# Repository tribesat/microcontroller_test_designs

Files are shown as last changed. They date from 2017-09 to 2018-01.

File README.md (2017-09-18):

# microcontroller_test_designs
Practice designing and manufacturing microcontroller boards

# License Information

The hardware is released under [Creative Commons Share-alike 3.0](http://creativecommons.org/licenses/by-sa/3.0/).  

## ATmega328P_QFP

These desgines are adapted from the [Sparkfun Arduino Pro Mini](https://github.com/sparkfun/Arduino_Pro_Mini_328)

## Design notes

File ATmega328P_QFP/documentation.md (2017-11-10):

# ATmega328P Quad Flat Pack (QFP)

This board was designed by the Tribesat Project in 2016. The purpose of this design was to test our ability to manufacture a board with an ATmega328P in a quad flat pack package.

The ATmega328P is an 8-bit AVR microcontroller. More information about it can be found [here](http://www.microchip.com/wwwproducts/en/ATmega328P).

The board desgine is derivied from the [Sparkfun Arduino Pro Mini](https://learn.sparkfun.com/tutorials/using-the-arduino-pro-mini-33v). The main difference between that board and this one is the removal of the voltage regulator and physical reset button. The pin out on this board is the same as the Arduino Pro Mini pin out.

This design can work with a 8Mhz or 16Mhz oscillator. If 16Mhz is used power the board at 5V, if 8Mhz is used the board may be powered at 3.3V.

Power must be regulated before entering into this board.

To reset the board, briefly short one of the RST pins to ground. The RST pins are  pulled high with a 10k resistor.

A green LED is connected to pin 13 for trouble shoting purposes. There is not power indicator LED.

The traces on the board are 0.01" and the vias have 0.02" drill holes. This is more than sufficient to handle the current through the traces. Right angles in the data traces have been avoided wherever possible.

The bottom and top layers of the board contain ground pours. These pores are connected through the GND pins and vias. These pores both insure good grounding in the board and isolate the oscillator from noise.

Decoupling capacitors were added as near to the chips as possible to minimize noise. This is detailed in the relevant data sheets.

0603 package size is used for all passive components. This size was selected because I believe it to be a good compromise between size and ease of placement.  The exception to this is the 10uF capacitor, which necessitated a larger package size.

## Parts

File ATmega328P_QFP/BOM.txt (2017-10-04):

component/value, size, quanity, digikey part number
--------------------------------------------------------
ATmega328P, 32-TQFP, 1, ATMEGA328P-AURCT-ND
8MHz Resonator, 3-SMD, 1, 490-1195-1-ND
0.1uF Capacitor, 0603, 4, 311-1088-1-ND
10uF Polarized Capacitor, 1206, 1, 478-1654-1-ND
10k Resistor, 0603, 1, 311-10.0KHRCT-ND
330 Resistor, 0603, 1, 311-330HRCT-ND
Green LED, 0603, 1, 350-2035-1-ND

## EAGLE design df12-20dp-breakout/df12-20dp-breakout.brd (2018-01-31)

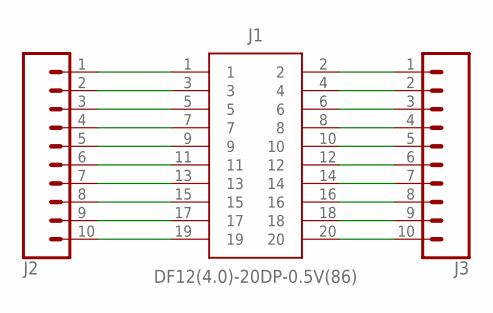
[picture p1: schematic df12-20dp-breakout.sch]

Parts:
J1: DF12(4.0)-20DP-0.5V(86); DF12(4.0)-20DP
J2, J3: CONN_10LOCK_LONGPADS; 1X10_LOCK_LONGPADS

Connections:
unnamed: J1.17, J2.9
unnamed: J1.15, J2.8
unnamed: J1.13, J2.7
unnamed: J1.11, J2.6
unnamed: J1.9, J2.5
unnamed: J1.7, J2.4
unnamed: J1.19, J2.10
unnamed: J1.5, J2.3
unnamed: J1.3, J2.2
unnamed: J1.1, J2.1
unnamed: J1.2, J3.1
unnamed: J1.4, J3.2
unnamed: J1.6, J3.3
unnamed: J1.8, J3.4
unnamed: J1.10, J3.5
unnamed: J1.12, J3.6
unnamed: J1.14, J3.7
unnamed: J1.16, J3.8
unnamed: J1.18, J3.9
unnamed: J1.20, J3.10

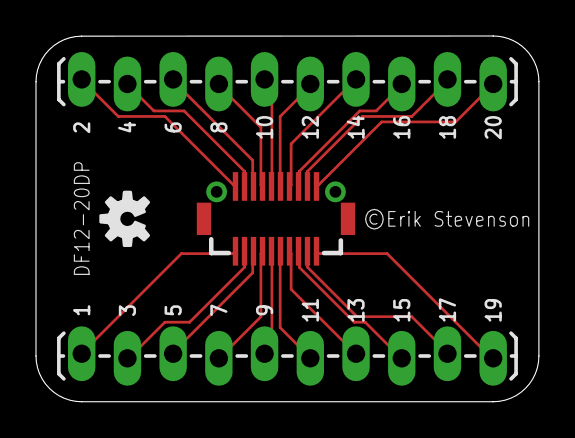
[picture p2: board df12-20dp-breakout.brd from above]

Board: 2 copper layers, 27.9 x 20.3 mm, 4 parts (0 on the bottom side), 20 nets.

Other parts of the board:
U$1: OSHW-LOGO-S

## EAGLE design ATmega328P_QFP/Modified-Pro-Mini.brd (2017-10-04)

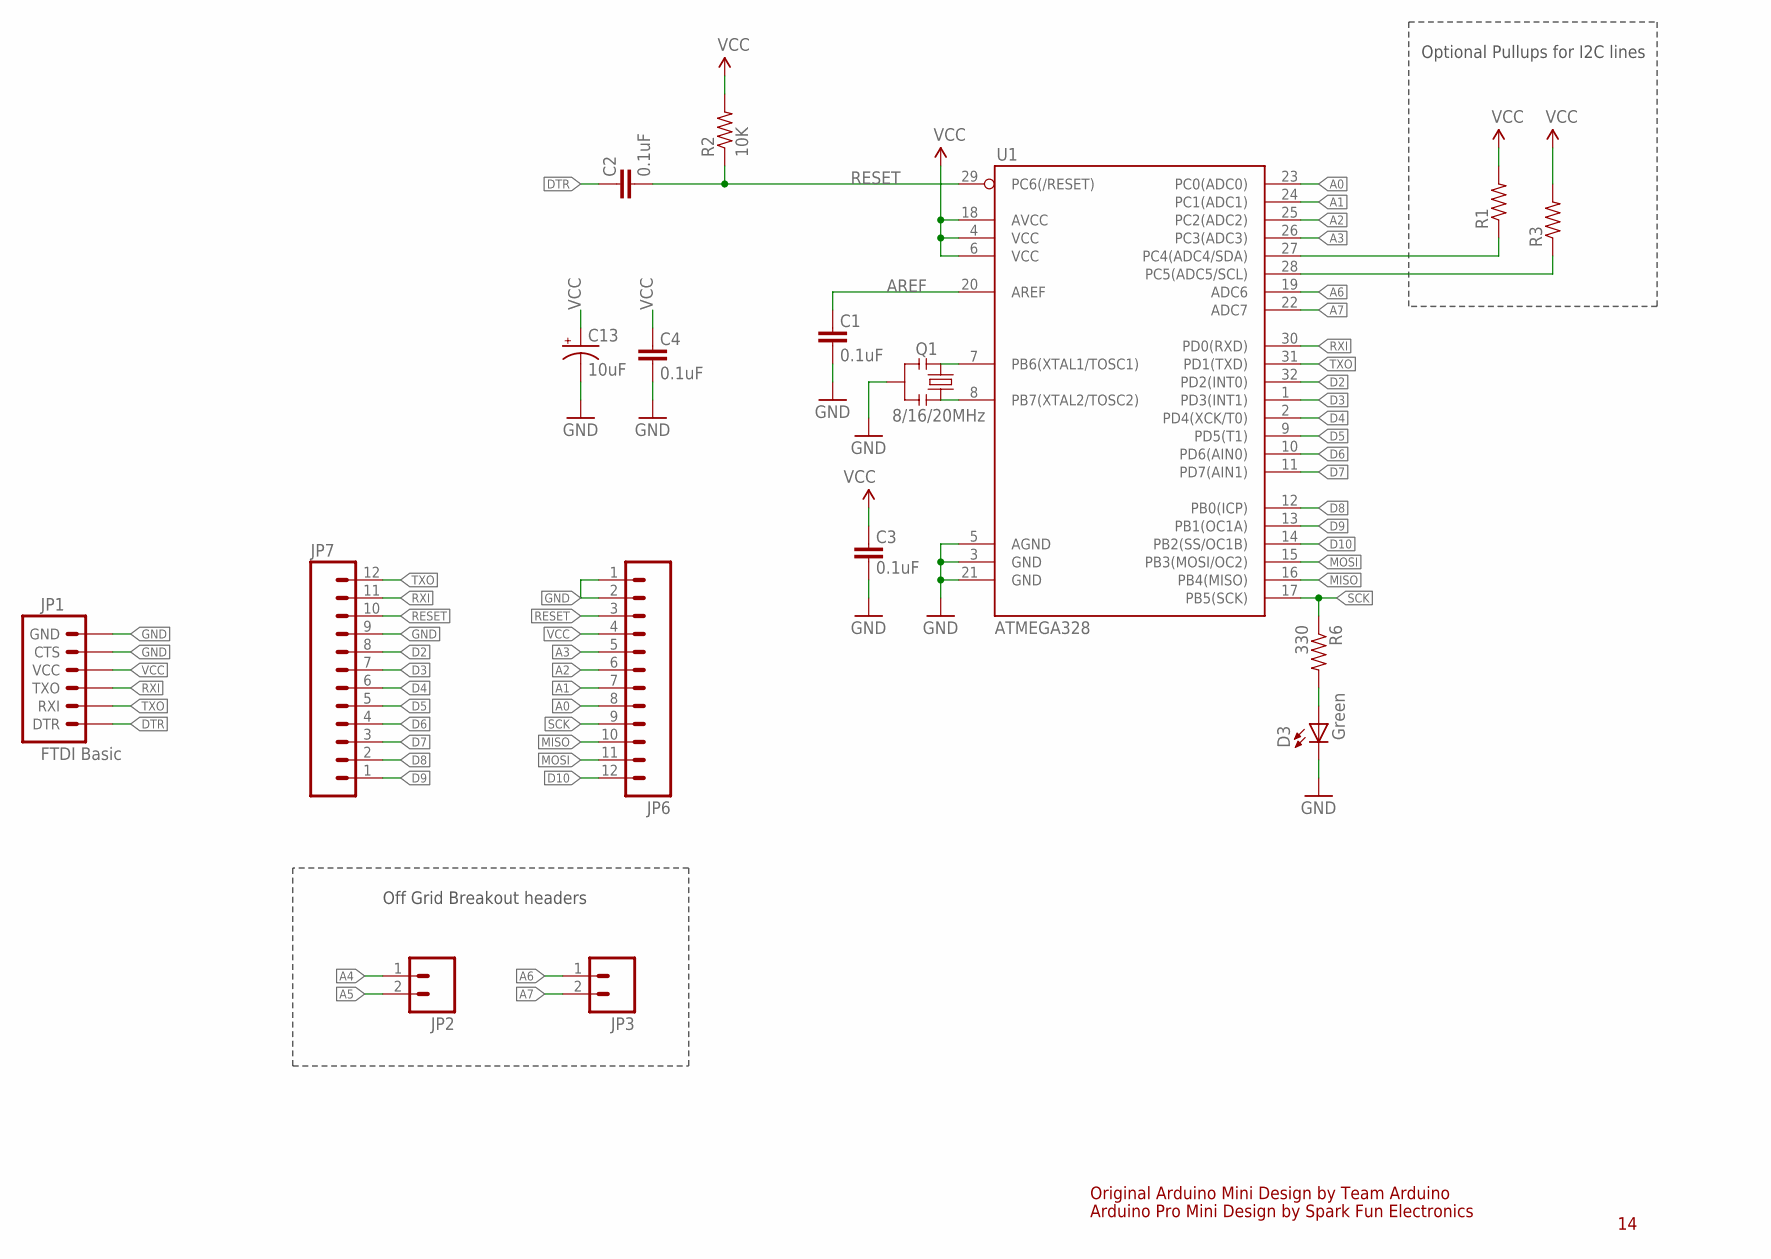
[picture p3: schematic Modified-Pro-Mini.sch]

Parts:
C1, C2, C3, C4: 0.1uF; 0603-CAP
C13: 10uF; EIA3216
D3: Green; 0603-LED-ALT1
JP1: FTDI Basic; 1X06
JP2, JP3: M02PTH; 1X02
JP6, JP7: M12PTH; 1X12
Q1: 8/16/20MHz; RESONATOR-SMD-1:1
R1, R3: RESISTOR0603-RES; 0603-RES
R2: 10K; 0603-RES
R6: 330; 0603-RES
U1: ATMEGA328; TQFP32-08

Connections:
A0: JP6.8, U1.23 (PC0(ADC0))
A1: JP6.7, U1.24 (PC1(ADC1))
A2: JP6.6, U1.25 (PC2(ADC2))
A3: JP6.5, U1.26 (PC3(ADC3))
A4: JP2.1, R1.1, U1.27 (PC4(ADC4/SDA))
A5: JP2.2, R3.1, U1.28 (PC5(ADC5/SCL))
A6: JP3.1, U1.19 (ADC6)
A7: JP3.2, U1.22 (ADC7)
AREF: C1.2, U1.20 (AREF)
D2: JP7.8, U1.32 (PD2(INT0))
D3: JP7.7, U1.1 (PD3(INT1))
D4: JP7.6, U1.2 (PD4(XCK/T0))
D5: JP7.5, U1.9 (PD5(T1))
D6: JP7.4, U1.10 (PD6(AIN0))
D7: JP7.3, U1.11 (PD7(AIN1))
D8: JP7.2, U1.12 (PB0(ICP))
D9: JP7.1, U1.13 (PB1(OC1A))
D10: JP6.12, U1.14 (PB2(SS/OC1B))
DTR: C2.2, JP1.1 (DTR)
GND: C1.1, C3.1, C4.1, C13.C (-), D3.C, JP1.5 (CTS), JP1.6 (GND), JP6.1, JP6.2, JP7.9, Q1.2, U1.3 (GND), U1.5 (AGND), U1.21 (GND)
MISO: JP6.10, U1.16 (PB4(MISO))
MOSI: JP6.11, U1.15 (PB3(MOSI/OC2))
unnamed: Q1.3, U1.8 (PB7(XTAL2/TOSC2))
unnamed: Q1.1, U1.7 (PB6(XTAL1/TOSC1))
unnamed: D3.A, R6.2
RESET: C2.1, JP6.3, JP7.10, R2.1, U1.29 (PC6(/RESET))
RXI: JP1.3 (TXO), JP7.11, U1.30 (PD0(RXD))
SCK: JP6.9, R6.1, U1.17 (PB5(SCK))
TXO: JP1.2 (RXI), JP7.12, U1.31 (PD1(TXD))
VCC: C3.2, C4.2, C13.A (+), JP1.4 (VCC), JP6.4, R1.2, R2.2, R3.2, U1.4 (VCC), U1.6 (VCC), U1.18 (AVCC)

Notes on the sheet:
Original Arduino Mini Design by Team Arduino
Arduino Pro Mini Design by Spark Fun Electronics
Optional Pullups for I2C lines
Off Grid Breakout headers

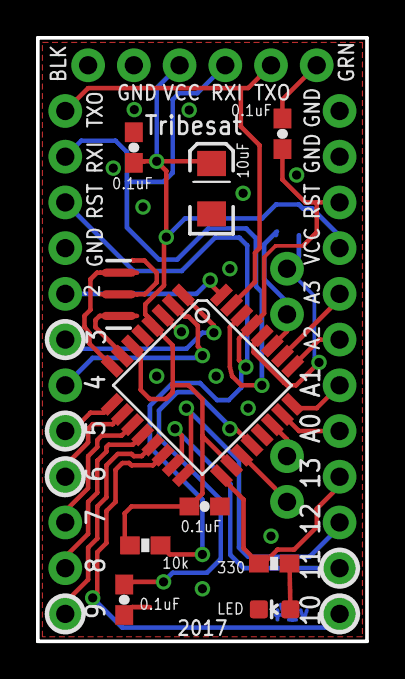
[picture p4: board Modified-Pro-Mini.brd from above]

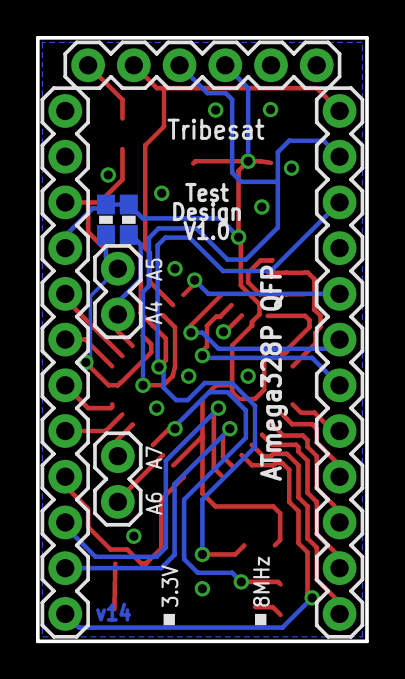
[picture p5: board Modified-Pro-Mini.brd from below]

Board: 2 copper layers, 18.3 x 33.5 mm, 17 parts (7 on the bottom side), 30 nets.

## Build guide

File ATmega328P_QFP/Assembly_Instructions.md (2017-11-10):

# Assembly Instructions

1. Clean PCB, stencil, jig, and tools with IPA
2. Place PCB into jig, and tape the jig together
3. Aligne the stencil with the PCB, and firmly tape the stencil onto the jig
4. Lightly tape the jig onto the table
5. Put a blop of solder paste onto the stencil near the slots for the 328p
6. Use the solder paste spreader to spread the blob of solder paste over the sentencil. Start by bring the paste over the 328p slots and then move outward on the sentencil to the other components
7. Remove the stencil from the jig
   * Be carful not to smear the paste during this process
8. Remove the jig from around the PCB
9. Use exacto knife and dental picks to clean up solder paste
   * Try to get a little bit of seperation between the solder paste on each pad
   * Make sure the solder paste isn't going to flow onto an vias or holes
   * It dosen't have to be perfect. The solder sheild on the purple portions of the PCB will cause the paste to flow to the copper when the paste is liquified in the oven
10. Place the 328p chip on the PCB
    * The white dot on the PCB corosponds to a dot on the 328p chip
11. Place the osicllator chip on the board. Be carful that it does not touch a pin on the microcontroller
    * Orientation does not matter on this component
12. Place the 0.1uF capacitor that is closest to the microcontroller, then place the rest of the 0.1uF capacitors
    * Orientation does not mater on these components
13. Place the 10kΩ and 330Ω resistors
    * Orientation does not mater on these components
14. Place the green LED
    * The green triangle on the bottom of the LED should aline with the triangle printed on the PCB
15. Place the 10uF capacitor
    * The dark line on the top of the capcitor should aline with the curved line on the PCB
16. Place board into the solder reflow oven, and run it
17. Remove board from the oven when it's cool
18. Visual inspect the board for shorts and bad connections
19. Use DMM to check for shorts between VCC and GND
    * To do this turn the DMM to messure restance and make sure the resistance is large
20. Use DMM to check for shorts between VCC and all other pins
    * Keep in mind that RST is pulled up, so there should only be 10kΩ between it and VCC
21. Use DMM to check for shorts between GND and all other pins
22. Hand solder header pins onto the board

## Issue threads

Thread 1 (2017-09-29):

Finish BOM for ATmega328P_QFP

WLaney, 2017-09-29:
The we need to get Digikey part numbers for the [ATmega328p QFP BOM](https://github.com/tribesat/microcontroller_test_designs/blob/master/ATmega328P_QFP/BOM.txt)

To do this look on Digikey for resistors and ceramic capacitors that are the right package size and value. We want the tolerance on the resistors to be around +/-1% and probably +/-5 or 10% on the caps.

Closed 2017-09-30.

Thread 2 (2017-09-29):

ATmega328P QFP Silk Tweeks

WLaney, 2017-09-29:
It is hard to tell if boards are going to come out looking right just from the silk screen layers in Eagle.

The best way to make sure that OSH park is going to print things the way we want it to just [upload the board](https://oshpark.com/uploads/new), and see it how it renders. Then make any necessary changes to the silk in Eagle, and re-upload.

This needs to be done for the [QFP board](https://github.com/tribesat/microcontroller_test_designs/tree/master/ATmega328P_QFP). Just upload it, and if anything doesn't look right on the silk layer move it around until it does.

WLaney, 2017-09-30:
#4

Closed 2017-09-30.

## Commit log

2017-09-18 added lightly modfied arduino pro mini
    this is the 328p QFP reference desgine
    removed physical reset button from the pro mini desgines
    [Arduino-Pro-Mini.brd, Arduino-Pro-Mini.sch]
2017-09-18 file rename
    [Modified-Pro-Mini.brd, Modified-Pro-Mini.sch]
2017-09-18 updated silk
    [Modified-Pro-Mini.brd, Modified-Pro-Mini.sch]
2017-09-18 removed power regulator
    [Modified-Pro-Mini.brd, Modified-Pro-Mini.sch]
2017-09-19 rerouted wires left by removed compoents
    [Modified-Pro-Mini.brd]
2017-09-19 changed raw pin to gnd
    [Modified-Pro-Mini.brd, Modified-Pro-Mini.sch]
2017-09-19 bumbed out all sides by 0.01in
    got board to pass OSH park DRC
    [Modified-Pro-Mini.brd]
2017-09-26 updated silk with board and part info
    [Modified-Pro-Mini.brd]
2017-09-26 added decoupling cap
    [Modified-Pro-Mini.brd, Modified-Pro-Mini.sch]
2017-09-29 palced decoupling cap
    [Modified-Pro-Mini.brd]
2017-09-29 created BOM, missing digikey part numbers
2017-09-29 fixed DRC errors
    [Modified-Pro-Mini.brd]
2017-09-30 Prepare silkscreen layers for OSH Park printing (#4)
    * Fix typo in bPlace layer
    * Remove fiducials
    * Cleared the tNames layer
    * Slight adjustments to prevent text from overlapping copper
    * got rid of kink in TXO line
    * moved via slightly
    * bottom silk tweak
    [Modified-Pro-Mini.brd, Modified-Pro-Mini.sch]
2017-10-02 added LED to 328P QFP BOM
2017-10-02 straigtened VCC line
    [Modified-Pro-Mini.brd]
2017-10-04 updated BOM part number
    0.1uF cap was 0603 metric, our measurements are in imperial
2017-10-28 created assembly instructions
2018-01-31 Df12 20dp breakout (#8)
    * Create df12-20dp breakout board design
    * Align pins to multiple of .1 for breadboard
    * Add silkscreen
    * Fix typo
    * Add df12-20dp footprint library file (#7)
    [df12-20dp-breakout.brd, df12-20dp-breakout.sch]

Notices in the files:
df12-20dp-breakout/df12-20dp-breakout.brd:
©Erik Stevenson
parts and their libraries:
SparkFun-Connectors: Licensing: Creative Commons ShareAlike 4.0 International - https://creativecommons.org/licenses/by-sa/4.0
